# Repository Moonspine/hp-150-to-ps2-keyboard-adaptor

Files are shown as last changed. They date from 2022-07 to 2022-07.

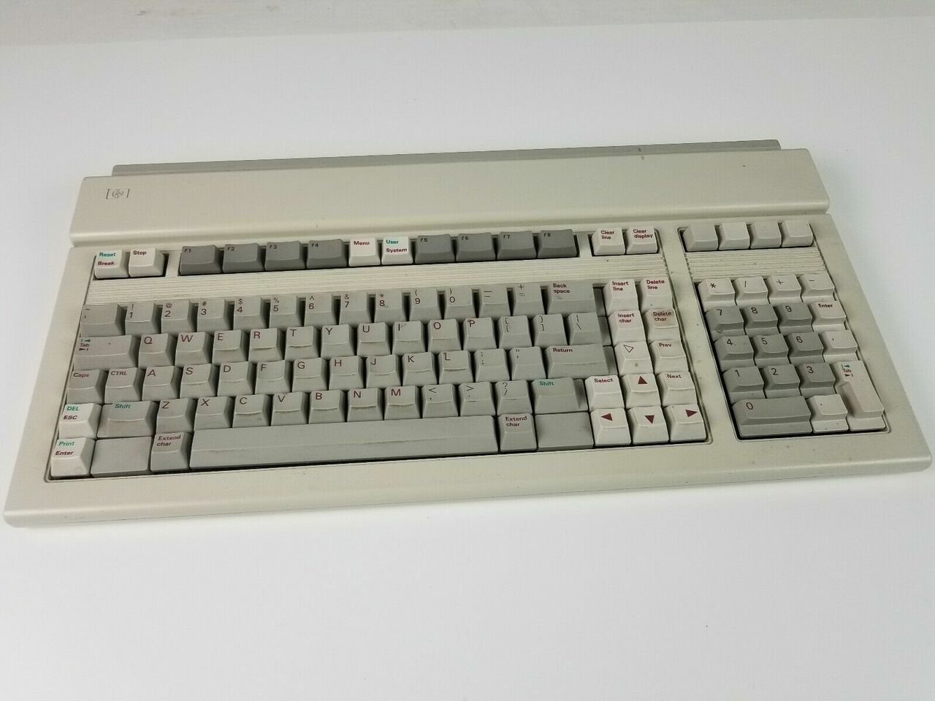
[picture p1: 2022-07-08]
s-l1600__48703.1562000548.jpg

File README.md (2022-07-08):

# hp-150-to-ps2-keyboard-adaptor
This project contains code and design files to build an adaptor that lets an HP-150 computer talk to a PS/2 keyboard.

## Purpose
I recently repaired and restored an old HP-150 computer from the brink of death.
After I finally got the video board working again, I realized that I couldn't do anything without a keyboard.
However, these keyboards are not a standard type (HP decided not to go with IBM PC compatibility on this one).
Checking the 'Net, I noticed that these keyboards sold for outrageous prices.
"Why not just adapt a PS/2 keyboard?" I wondered. So I dug into the schematics and wrote an Arduino program to read a PS/2 keyboard and pretend to be an HP-150 keyboard.

## Which computers can use this?
The [HP-150](http://hpmuseum.net/display_item.php?hw=43). It's a nifty little touchscreen computer from 1983.
I'm uncertain if this will work with of HP's other oddball nonstandard computers (possibly other computers in their 100 series).
So... it's a pretty niche project.
If you do use this with another computer, let me know, and I'll add it to this list.

## How do I make one?
First, you'll want to make a PCB. This can be done cheaply via your favorite Chinese PCB manufacturer (as of this writing, mine is [JLCPCB](https://jlcpcb.com/), #NotSponsored).
The Gerber files are already premade for you (in the [Gerber](Gerber) folder in this repository). But if you want to modify the board before manufacture, the design files are in the [Board](Board) folder (I used [KiCad 6](https://www.kicad.org/download/) to create them).

Second, you'll need to assemble the board. I recommend checking the schematics in [Board](Board) to see the exact part values I used. You can get some RJ-12 cables and connectors and PS/2 connectors from Amazon or eBay as well.

Third, you'll need to burn the program to an ATMEGA328p. There are many ways to do this, but I used an ICSP to program via the ICSP header on the board using Arduino 1.8.12

There are a couple of optional steps, too!

First, you can print an enclosure to hold the PCB and protect it from dust and your own clumsiness. I definitely did this.
The files are in [3D Printing](3D Printing), and if you happen to have a Photon Mono X 6K, you can use those *.pwmb files directly. Otherwise, you'll need to use the STL files and do what you do best.
The screws that hold the case together are meant to be M3 screws with brass inserts in the bottom of the case, but you can modify this design to fit whatever you want to do.

The second optional step is to print the [keyboard decals](Keyboard Decals.xcf) and affix them to the specialty keys on your PS/2 keyboard (see the [keymap](Keymap.txt) for details on how I set these up by default).
You can always remap these keys by modifying the program (specifically [ps2_to_hp_map.h](Code/PS2_Keyboard_Adaptor/ps2_to_hp_map.h))

## License
This entire project is licensed under the MIT license. Feel free to do whatever with it! If it helps even one person, then it was a good idea for me to upload it to Github.

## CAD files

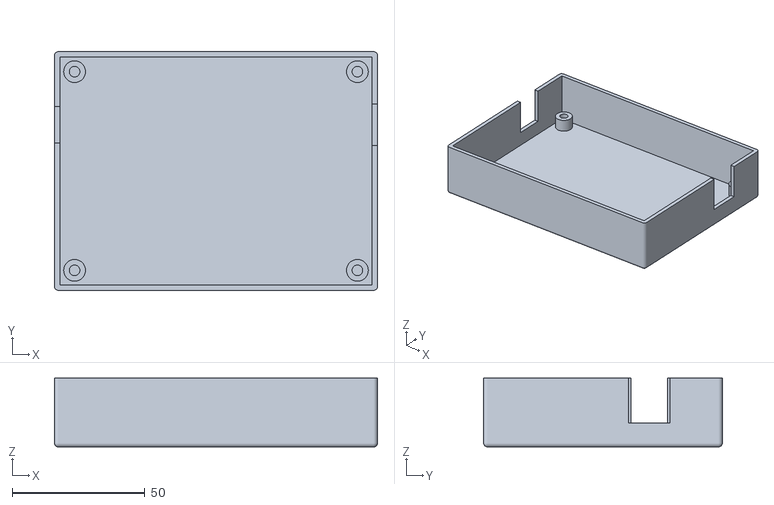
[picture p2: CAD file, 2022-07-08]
3D Printing/PS2_Keyboard_Adaptor_Box_Base.stl
121.8 x 90.1 x 26.0

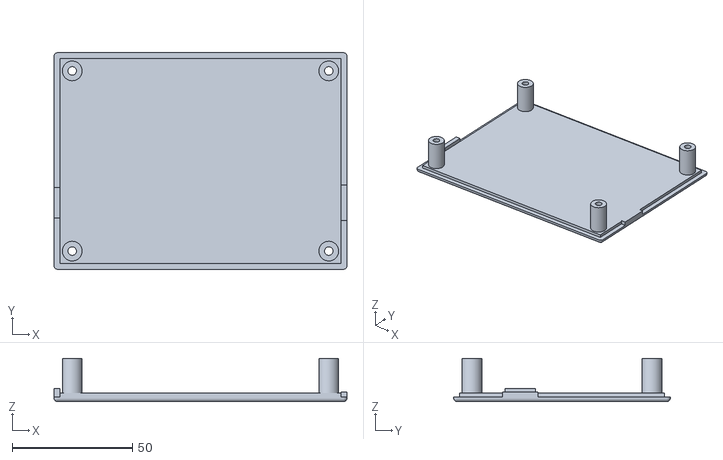
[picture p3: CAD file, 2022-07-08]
3D Printing/PS2_Keyboard_Adaptor_Box_Lid.stl
121.8 x 90.1 x 18.0

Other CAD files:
3D Printing/PS2_Keyboard_Adaptor_Box.blend

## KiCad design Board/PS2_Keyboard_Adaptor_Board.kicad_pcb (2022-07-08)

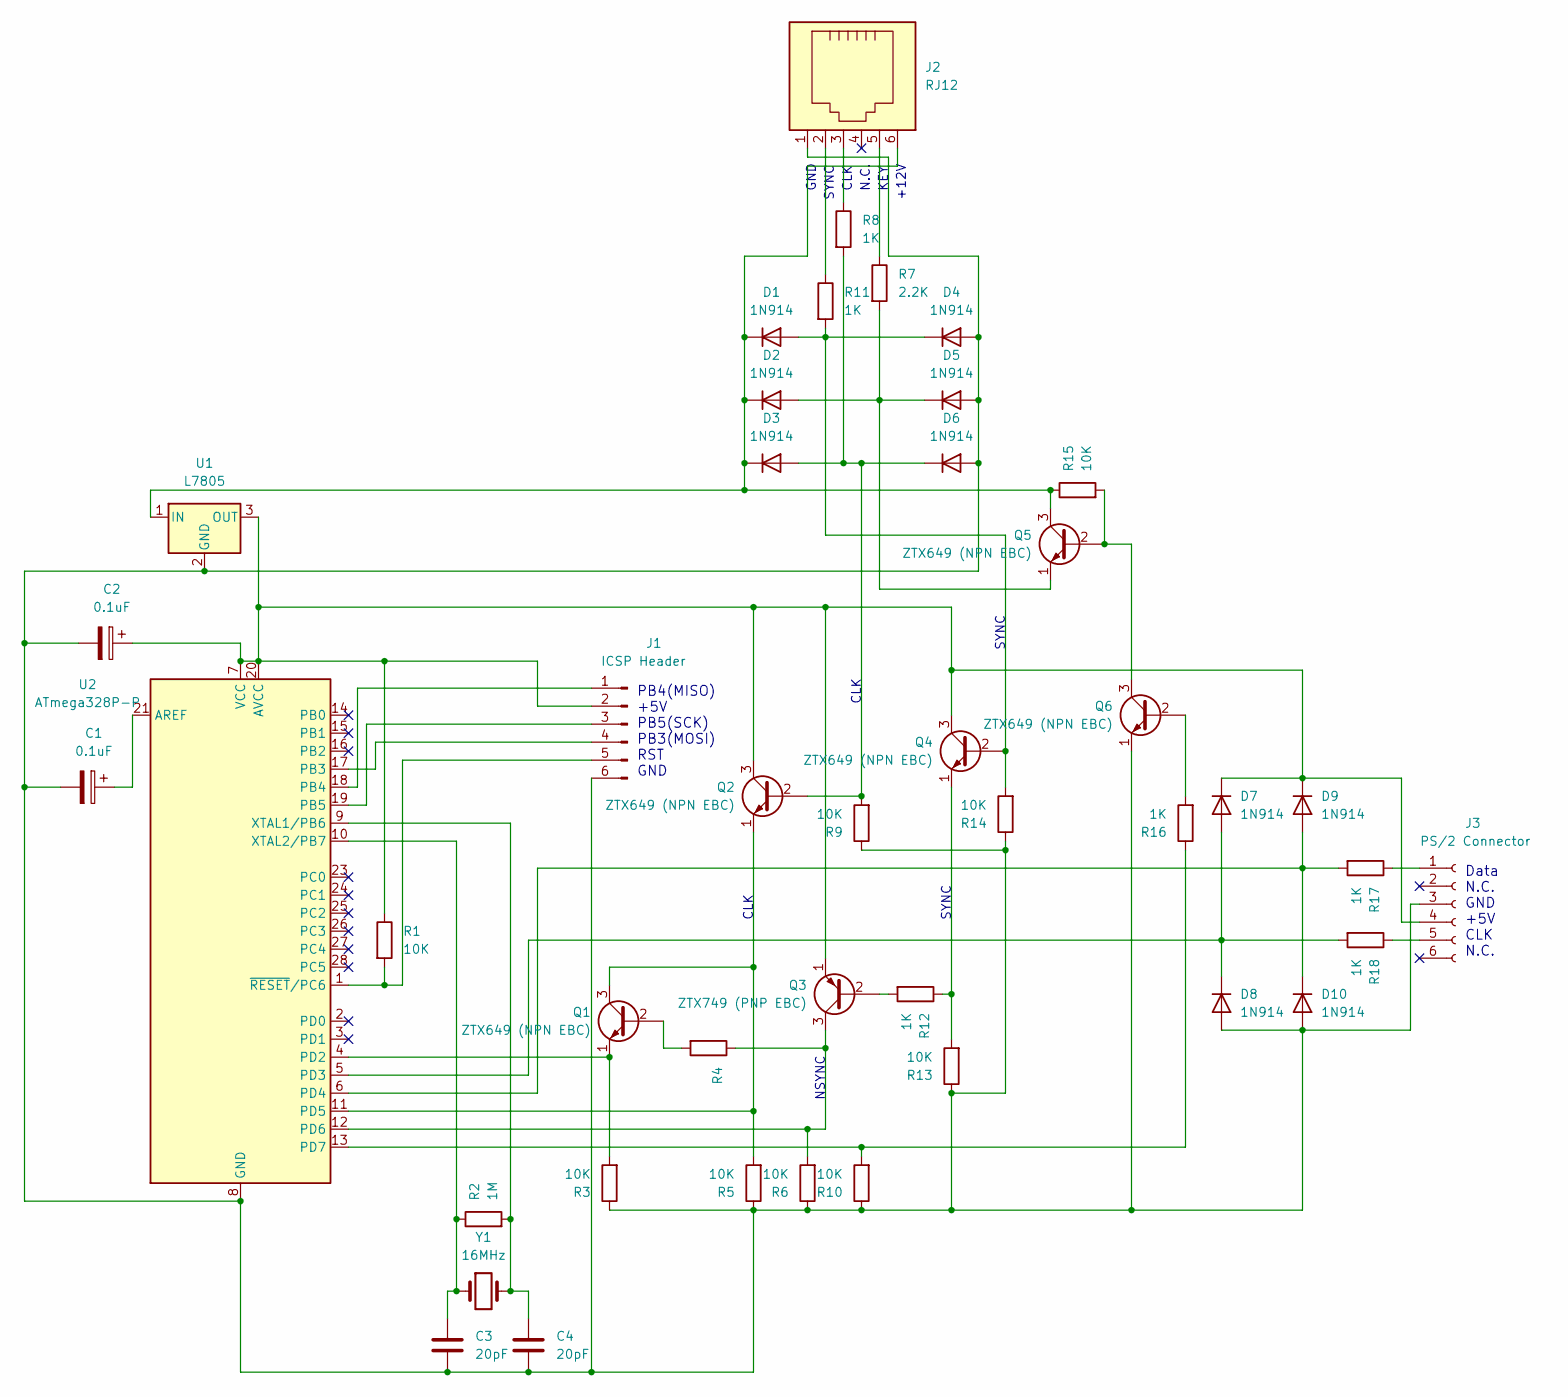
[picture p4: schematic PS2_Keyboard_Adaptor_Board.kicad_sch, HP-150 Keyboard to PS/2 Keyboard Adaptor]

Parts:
C1, C2: 0.1uF; CP_Radial_Tantal_D5.0mm_P2.50mm
C3, C4: 20pF; C_Disc_D5.0mm_W2.5mm_P2.50mm
D1, D2, D3, D4, D5, D6, D7, D8, D9, D10: 1N914; D_DO-34_SOD68_P7.62mm_Horizontal
J1: ICSP Header; PinHeader_2x03_P2.54mm_Vertical
J2: RJ12; RJ12_Amphenol_54601
J3: PS/2 Connector; PS2_Connector_F
Q1, Q2, Q4, Q5, Q6: ZTX649 (NPN EBC); TO-92L_Inline
Q3: ZTX749 (PNP EBC); TO-92_Inline
R1, R3, R5, R6, R9, R10, R13, R14, R15: 10K; R_Axial_DIN0207_L6.3mm_D2.5mm_P10.16mm_Horizontal
R2: 1M; R_Axial_DIN0207_L6.3mm_D2.5mm_P10.16mm_Horizontal
R4: R_Axial_DIN0207_L6.3mm_D2.5mm_P10.16mm_Horizontal
R7: 2.2K; R_Axial_DIN0207_L6.3mm_D2.5mm_P10.16mm_Horizontal
R8, R11, R12, R16, R17, R18: 1K; R_Axial_DIN0207_L6.3mm_D2.5mm_P10.16mm_Horizontal
U1: L7805; TO-220-3_Vertical
U2: ATmega328P-P; DIP-28_W7.62mm
Y1: 16MHz; Crystal_HC49-U_Vertical

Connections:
unnamed: C1.1, U2.21 (AREF)
unnamed: C1.2, C2.2, C3.2, C4.2, D4.2 (A), D5.2 (A), D6.2 (A), D8.2 (A), D10.2 (A), J1.6, J2.1, J3.3, Q6.1 (E), R3.1, R5.1, R6.1, R9.1, R10.1, R13.1, R14.1, U1.2 (GND), U2.8 (GND), U2.22 (GND)
unnamed: C2.1, D7.1 (K), D9.1 (K), J1.2, J3.4, Q2.3 (C), Q3.1 (E), Q4.3 (C), R1.1, U1.3 (OUT), U2.7 (VCC), U2.20 (AVCC)
unnamed: C3.1, R2.1, U2.10 (XTAL2/PB7), Y1.1
unnamed: C4.1, R2.2, U2.9 (XTAL1/PB6), Y1.2
unnamed: D1.1 (K), D2.1 (K), D3.1 (K), J2.6, Q5.3 (C), R15.1, U1.1 (IN)
unnamed: D1.2 (A), D4.1 (K), Q4.2 (B), R11.2, R14.2
unnamed: D2.2 (A), D5.1 (K), Q5.1 (E), R7.2
unnamed: D3.2 (A), D6.1 (K), Q2.2 (B), R8.2, R9.2
unnamed: D7.2 (A), D8.1 (K), R18.2, U2.5 (PD3)
unnamed: D9.2 (A), D10.1 (K), R17.2, U2.6 (PD4)
unnamed: J1.1, U2.18 (PB4)
unnamed: J1.3, U2.19 (PB5)
unnamed: J1.4, U2.17 (PB3)
unnamed: J1.5, R1.2, U2.1 (~RESET/PC6)
unnamed: J2.2, R11.1
unnamed: J2.3, R8.1
unnamed: J2.5, R7.1
unnamed: J3.1, R17.1
unnamed: J3.5, R18.1
unnamed: Q1.1 (E), R3.2, U2.4 (PD2)
unnamed: Q1.2 (B), R4.2
unnamed: Q1.3 (C), Q2.1 (E), R5.2, U2.11 (PD5)
unnamed: Q3.2 (B), R12.2
unnamed: Q3.3 (C), R4.1, R6.2, U2.12 (PD6)
unnamed: Q4.1 (E), R12.1, R13.2
unnamed: Q5.2 (B), Q6.3 (C), R15.2
unnamed: Q6.2 (B), R16.2
unnamed: R10.2, R16.1, U2.13 (PD7)

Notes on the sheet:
GND
CLK
NSYNC
SYNC
KEY
Data N.C. GND +5V CLK N.C.
PB4(MISO) +5V PB5(SCK) PB3(MOSI) RST GND
N.C.
+12V

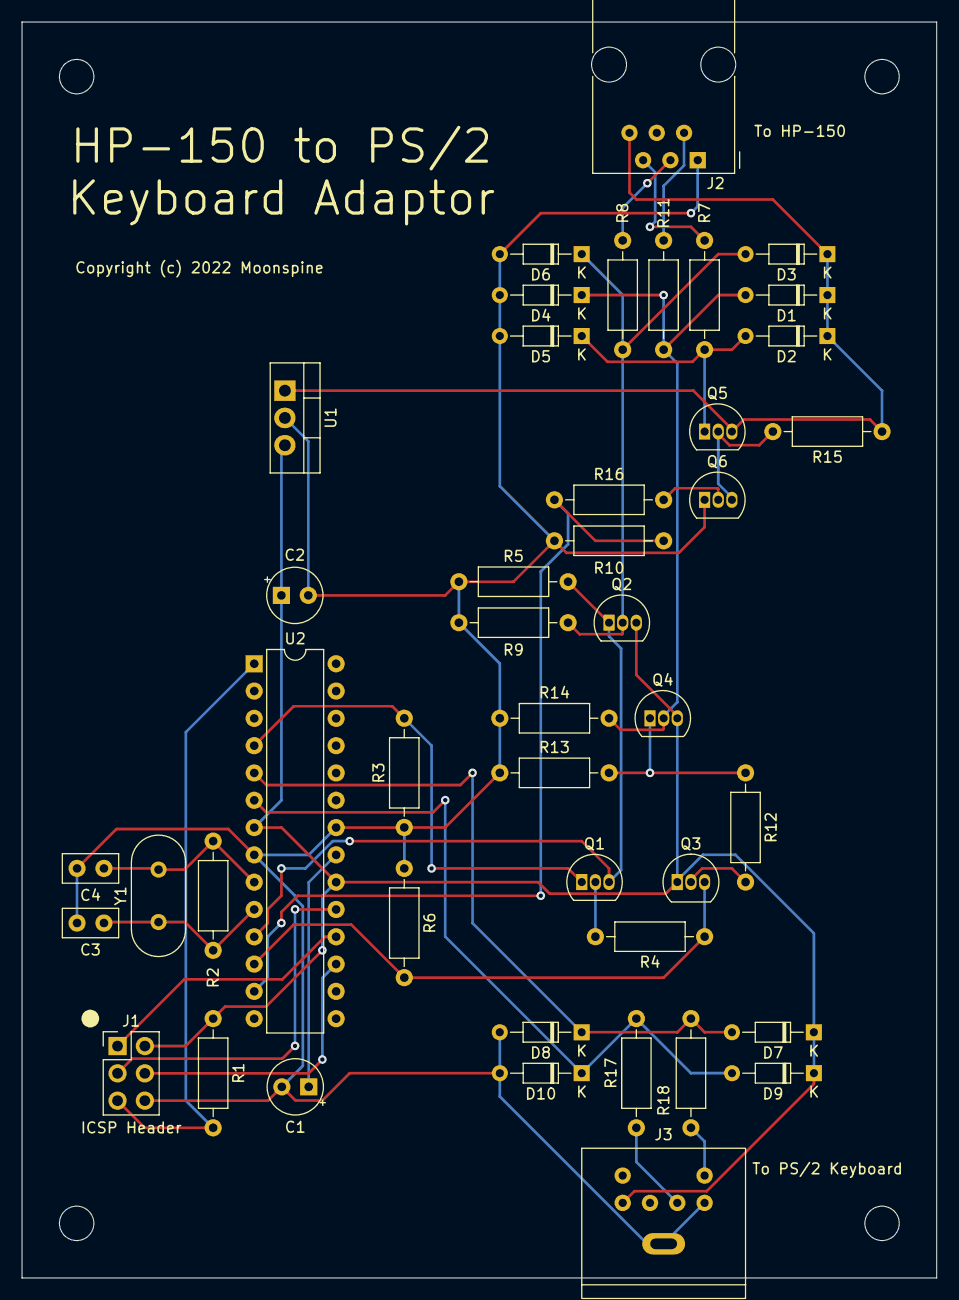
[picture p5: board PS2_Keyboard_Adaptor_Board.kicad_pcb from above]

Board: 2 copper layers, 85.1 x 116.8 mm, 44 parts (0 on the bottom side), 29 nets.

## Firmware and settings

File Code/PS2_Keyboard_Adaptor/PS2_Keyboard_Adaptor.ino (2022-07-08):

#include "PS2KeyAdvanced.h"

#include "hp_key_defines.h"
#include "ps2_to_hp_map.h"

// All HP keyboard signals are +12V max, so the Arduino needs some supporting circuitry for level shifting! (See schematic)
// HP_SYNC and HP_DATA_OUT are inverted (see schematic)

#define PS2_IRQ 3
#define PS2_DATA 4

#define HP_IRQ 2
#define HP_CLK 5
#define HP_SYNC 6
#define HP_DATA_OUT 7

#define HP_CLK_BIT (1 << HP_CLK)
#define HP_SYNC_BIT (1 << HP_SYNC)
#define HP_DATA_OUT_BIT (1 << HP_DATA_OUT)

// Used particularly by HP_KEY_RESET to auto-break after a set number of keyboard frames
#define HP_KEY_BREAK_FRAMES 5


PS2KeyAdvanced ps2Keyboard;

// This is the HP keyboard state.
// Every entry in this array is one bit of keyboard data.
// The first 8 entries need to always be zero (these do not correspond to any HP keys).
// The last 8 entries need to mostly be zero, with the exception of 0x7c, which must always be 1.
volatile uint8_t keyboardState[128];
volatile uint8_t hpClockCount;


void setup() {
  // Initial keyboard state
  for (int i = 0; i < 128; ++i) {
    keyboardState[i] = 0;
  }
  keyboardState[0x7c] = 1;
  hpClockCount = 0;

  pinMode(HP_IRQ, INPUT);
  pinMode(HP_CLK, INPUT);
  pinMode(HP_SYNC, INPUT);
  pinMode(HP_DATA_OUT, OUTPUT);

  attachInterrupt(digitalPinToInterrupt(HP_IRQ), handleHPInterrupt, FALLING);
  ps2Keyboard.begin(PS2_DATA, PS2_IRQ);
}

void loop() {
  if (ps2Keyboard.available()) {
    uint16_t data = ps2Keyboard.read();
    uint8_t code = static_cast<uint8_t>(data & 0xff);
    uint8_t hpKey = pgm_read_byte(PS2_TO_HP_MAP + code);
    if (hpKey > 0) {
      keyboardState[hpKey] = (data & PS2_BREAK) > 0 ? 0 : HP_KEY_BREAK_FRAMES;
    }
  }
}

void handleHPInterrupt() {
  if ((PIND & HP_SYNC_BIT) == 0) {
    hpClockCount = 0;

    // This key code has no break, so we have to break it ourselves. Why not at a keyboard frame?
    if (keyboardState[HP_KEY_RESET] > 0) {
      --keyboardState[HP_KEY_RESET];
    }
  } else {
    hpClockCount = (hpClockCount + 1) & 0x7f;
    if (keyboardState[hpClockCount] > 0) {
      PORTD = PORTD & ~HP_DATA_OUT_BIT;
    } else {
      PORTD = PORTD | HP_DATA_OUT_BIT;
    }
  }
}

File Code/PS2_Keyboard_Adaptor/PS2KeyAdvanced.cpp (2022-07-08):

#define NO_LOCK_KEY_HANDLING

/* Version V1.0.9
  PS2KeyAdvanced.cpp - PS2KeyAdvanced library
  Copyright (c) 2007 Free Software Foundation.  All right reserved.
  Written by Paul Carpenter, PC Services <sales@pcserviceselectronics.co.uk>
  Created September 2014
  Updated January 2016 - Paul Carpenter - add tested on Due and tidy ups for V1.5 Library Management
    January 2020   Fix typos, correct keyboard reset status improve library.properties 
		   and additional platform handling and some documentation
    March 2020  Add SAMD1 as recognised support as has been tested by user
                Improve different architecture handling
    November 2020 Add support for STM32 from user Hiabuto-de
                  Tested on STM32Duino-Framework and PlatformIO on STM32F103C8T6 and an IBM Model M
    July 2021   Add workaround for ESP32 issue with Silicon (hardware) from user submissions

  IMPORTANT WARNING
 
    If using a DUE or similar board with 3V3 I/O you MUST put a level translator 
    like a Texas Instruments TXS0102 or FET circuit as the signals are 
    Bi-directional (signals transmitted from both ends on same wire).
 
    Failure to do so may damage your Arduino Due or similar board.

  Test History
    September 2014 Uno and Mega 2560 September 2014 using Arduino V1.6.0
    January 2016   Uno, Mega 2560 and Due using Arduino 1.6.7 and Due Board 
                    Manager V1.6.6
                    

  Assumption - Only ONE keyboard added to one Arduino
             - No stream support

  This is for a LATIN style keyboard using Scan code set 2. See various
  websites on what different scan code sets use. Scan Code Set 2 is the
  default scan code set for PS2 keyboards on power up.

  Fully featured PS2 keyboard library to provide
    All keys as a keycode (A-Z and 0-9 as ASCII equivalents)
    All function and movement keys supported even multi-lingual
    Parity checking of data sent/received on receive request keyboard resend
    Resends data when needed handles keyboard protocol for RESEND and ECHO
    Functions for get and set of
        Scancode set in use READ only
        LED and LOCK control
        ReadID
        Reset keyboard
        Send ECHO
        Handles NUM, _CAPS and SCROLL lock keys to LEDs
        Handles NUM/SCROLL internally

  Returns an uint16_t containing
        Make/Break status
        CAPS status
        SHIFT, CTRL, ALT, ALT GR, GUI keys
        Flag for function key not a displayable/printable character
        8 bit key code

    Code Ranges(bottom byte of uint16_t) see PS2KeyAdvanced.h for details
        0       invalid/error
        1-1F    Functions (_CAPS, _SHIFT, _ALT, Enter, DEL... )
        1A-1F   Functions with ASCII control code
                    (DEL, BS, TAB, ESC, ENTER, SPACE)
        20-60   Printable characters noting
                    0-9 = 0x30 to 0x39 as ASCII
                    A to Z = 0x41 to 0x5A as upper case ASCII type codes
                    8B Extra European key
        61-A0   Function keys and other special keys (plus F2 and F1 less 8B)
                    61-78 F1 to F24
                    79-8A Multimedia
                    8C-8E ACPI power
                    91-A0 and F2 and F1 - Special multilingual
        A8-FF   Keyboard communications commands (note F2 and F1 are special
                codes for special multi-lingual keyboards)

    By using these ranges it is possible to perform detection of any key and do
    easy translation to ASCII/UTF-8 avoiding keys that do not have a valid code.

    Top Byte is 8 bits denoting as follows with defines for bit code

        Define name bit     description
        PS2_BREAK   15      1 = Break key code
                   (MSB)    0 = Make Key code
        PS2_SHIFT   14      1 = Shift key pressed as well (either side)
                            0 = NO shift key
        PS2_CTRL    13      1 = Ctrl key pressed as well (either side)
                            0 = NO Ctrl key
        PS2_CAPS    12      1 = Caps Lock ON
                            0 = Caps lock OFF
        PS2_ALT     11      1 = Left Alt key pressed as well
                            0 = NO Left Alt key
        PS2_ALT_GR  10      1 = Right Alt (Alt GR) key pressed as well
                            0 = NO Right Alt key
        PS2_GUI      9      1 = GUI key pressed as well (either)
                            0 = NO GUI key
        PS2_FUNCTION 8      1 = FUNCTION key non-printable character (plus space, tab, enter)
                            0 = standard character key

  Error Codes
     Most functions return 0 or 0xFFFF as error, other codes to note and
     handle appropriately value in bottom byte
        0xAA   keyboard has reset and passed power up tests
               will happen if keyboard plugged in after code start
        0xFC   Keyboard General error or power up fail

  It is responsibility of your programme to deal with converting special cases
  like <_CTRL>+<ENTER> sends a special code to something else. A better method
  is to use PS2KeyMap library and add your own table to that library. If you
  wish to do that make a NEW library called SOMETHING different NOT a variant
  or revision of this one, as you are changing base functionality

  See PS2KeyCode.h for codes from the keyboard this library uses to decode.
  (may disappear in updates do not rely on this file or definitions)

  See PS2KeyAvanced.h for returned definitions of Keys and accessible
  definitions

  See PS2KeyMap.h for tables currently supported

  To get the key as ASCII/UTF-8 single byte character conversion requires use
  of PS2KeyMap library AS WELL.

  This library is free software; you can redistribute it and/or
  modify it under the terms of the GNU Lesser General Public
  License as published by the Free Software Foundation; either
  version 2.1 of the License, or (at your option) any later version.

  This library is distributed in the hope that it will be useful,
  but WITHOUT ANY WARRANTY; without even the implied warranty of
  MERCHANTABILITY or FITNESS FOR A PARTICULAR PURPOSE.  See the GNU
  Lesser General Public License for more details.

  You should have received a copy of the GNU Lesser General Public
  License along with this library; if not, write to the Free Software
  Foundation, Inc., 51 Franklin St, Fifth Floor, Boston, MA  02110-1301  USA
*/
#include <Arduino.h>
// Internal headers for library defines/codes/etc
#include "PS2KeyAdvanced.h"
#include "PS2KeyCode.h"
#include "PS2KeyTable.h"


// Private function declarations
void send_bit( void );
void send_now( uint8_t );
int16_t send_next( void );
void ps2_reset( void );
uint8_t decode_key( uint8_t );
void pininput( uint8_t );
void set_lock( );
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

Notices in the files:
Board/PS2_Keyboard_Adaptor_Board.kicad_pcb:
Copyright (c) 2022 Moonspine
